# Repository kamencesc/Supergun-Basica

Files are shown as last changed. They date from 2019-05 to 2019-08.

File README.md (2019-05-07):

# Supergun-Basica
Diseño de una Supergun básica.

## Que es un Supergun?
Un Supergun nos permite conectar las antiguas placas de máquinas recreativas a un sistema adaptado, como puede ser a una TV, un monitor LCD, usando Gamepads de consolas, etc...

## Que hace este Supergun?
Tengo otro repositorio en el que intento crear una supergun lo mas completa posible, pero todo empieza por una base y este reprositorio es ela base del otro, por lo tanto tiene unas prestaciones muy básicas, como su propio nombre indica.

Dos puertos para joysticks arcade de 6 botones, 4 direcciones, Start y Select.

Entrada de 6 pins para conecta un Kick Harness.

Botón para seleccionar si jugar con el botón 6 del Kick Harness o de la placa arcade (ej. Bluelf)

Cambio de botones via hardware, nos permite poder cambiar la entre dos distribuciones de botones en el caso de usar un CPO del tipo 6 botones como los de Capcom. Mediante este cambio podemos asignar los 6 botones para usar un juego de lucha de Capcom (modo normal) o bien usar los dos primeros botones de la izquierda de las dos hileras, para juegos de lucha de NeoGeo de 4 botones. **Es importante que los switch estén siempre en la misma posición para evitar doblepulsación**

Salida Jack de 3,5" con selector para audio MONO o STEREO

Salida de video mediante terminales de tornillo, directa del connector JAMMA para su posprocesado externo (ej. usando una GBS8200 y adaptar video de CGA a VGA)

Entrada de corriente mediante terminales de tornillo, +5V +12V -5V y GND. Los -5V no suelen usarse pero lo dejamos por si alguna placa lo requiere.

La placa integra un connector para Kick Harness de CPS2 y así no tener que ir haciendo bricolaje. Este connector tiene que ir arrimado a la derecha del Kick Harness en el modulo CPS2.

Para facilitar la manipulación, se pueden usar switch/palancas externas, por ejemplo en una caja o en un mueble arcade, para así tener mas accesible la configuración de botones o los botones Credit, Test, Servicio y Select+ (cambio de juego en MVS multi cartucho).

# Agradecimientos
En este proyecto se ha usado el conector Jamma disponible en **Shinichi-Ohki** y disponible en su GitHub: https://github.com/Shinichi-Ohki/JAMMA_connector_for_eagle

Teneis un fork de su proyecto en mi github en el que he integrado conectores inversos (los que usa este supergun) y he suprimido el texto (que ademas tenia en la misma cara y lo hacía inteligible): https://github.com/kamencesc/JAMMA_connector_for_eagle

Los "pañeros" de _Crazy Lab_ por aguantar mis preguntas tontas...

**UNTESTED**

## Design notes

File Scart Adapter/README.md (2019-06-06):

# Scart Adapter (jamma rgb2scart)
Con este adaptador tendremos señal de salida en SCART lista para connectar a una TV (no todas son compatibles).

Solo tenemos que llevar los siguientes señales

* R G B
* Sync
* 12V
* Audio R y L (con opción de usar un cable jack-jack, ideal por si usamos placas con salida de audio estereo directo como puede ser CPS2 o algunas MVS)

En la última versión disponible se ha añadido un LM1881 (AKA Sync Stripper) con montaje completamente opcional. El LM1881 usará el canal GREEN (sync on green) para generar una señal de sync mas limpia.

Para que el circuito funcioné como tal deberemos tener los jumpers J1 en posición 1-2 (o un switch si lo prefieres), los componentes son LM1881 en formato DIP8, dos condensadores de 0.1pF, una resistencia de 680k y por seguridad se ha añadido un REG1117 para usar 5V en el LM1881 (aunque tiene una tolerancia de 5-12V)

**UNTESTED**

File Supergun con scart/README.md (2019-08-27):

## Supergun con Scart
**UNTESTED**

Se ha realizado una versión del supergun con scart integrado. Este incluye todo lo del supergun básico ~~excepto que en vez de tener los terminales de RGB, disponemos de salida scart~~, seguimos disfrutando de salida jack 3.5" para el audio, si conectamos un jack, el audio del Scart queda deshabilitado.

Se han incluido Screw Terminals para dar salida a la señal directa del connector jamma, ademas de tener un selector de Sync, podemos seleccionar salida desde el potenciometro R10 o directo del jamma. En caso de usar los Screw Terminals y no se quiere instalar el scart, R5, R6, R7, R8 y R9 son completamente prescindibles.

~~Por espacio no se ha añadido un LM1881, sin prescindir de alguna otra opción no hay sitio en el diseño actual de la placa, se podria añadir a modo SMD pero lo que se pretende con esta placa es que sea de fácil montaje, con todos sus componentes DIP (con agujero).~~

Se ha añadido un LM1881 para Syn On Green en el scart, ademas hay un switch para seleccionar usar el LM1881 (CSYNC) o sync directo de jamma, esta última opción es para facilitar el uso con el OSSC.

Al igual que la versión básica se mantiene el Kick Harness para CPS2 (este Kick Harness es solo para los botones de patada y volumen, no para juegos de 4 Players), simplemente recortar las 2 placas adicionales, Soldar los pinheader correspondientes (hembra para la parte de CPS2 y la del supergun depende del usuario), soldar entre ellas los botones de patada del P1 y P2. La parte de CPS2 tiene para mapear botones de volumen (V- y V+).

Añadir que no todas las TVs pueden ser compatibles.

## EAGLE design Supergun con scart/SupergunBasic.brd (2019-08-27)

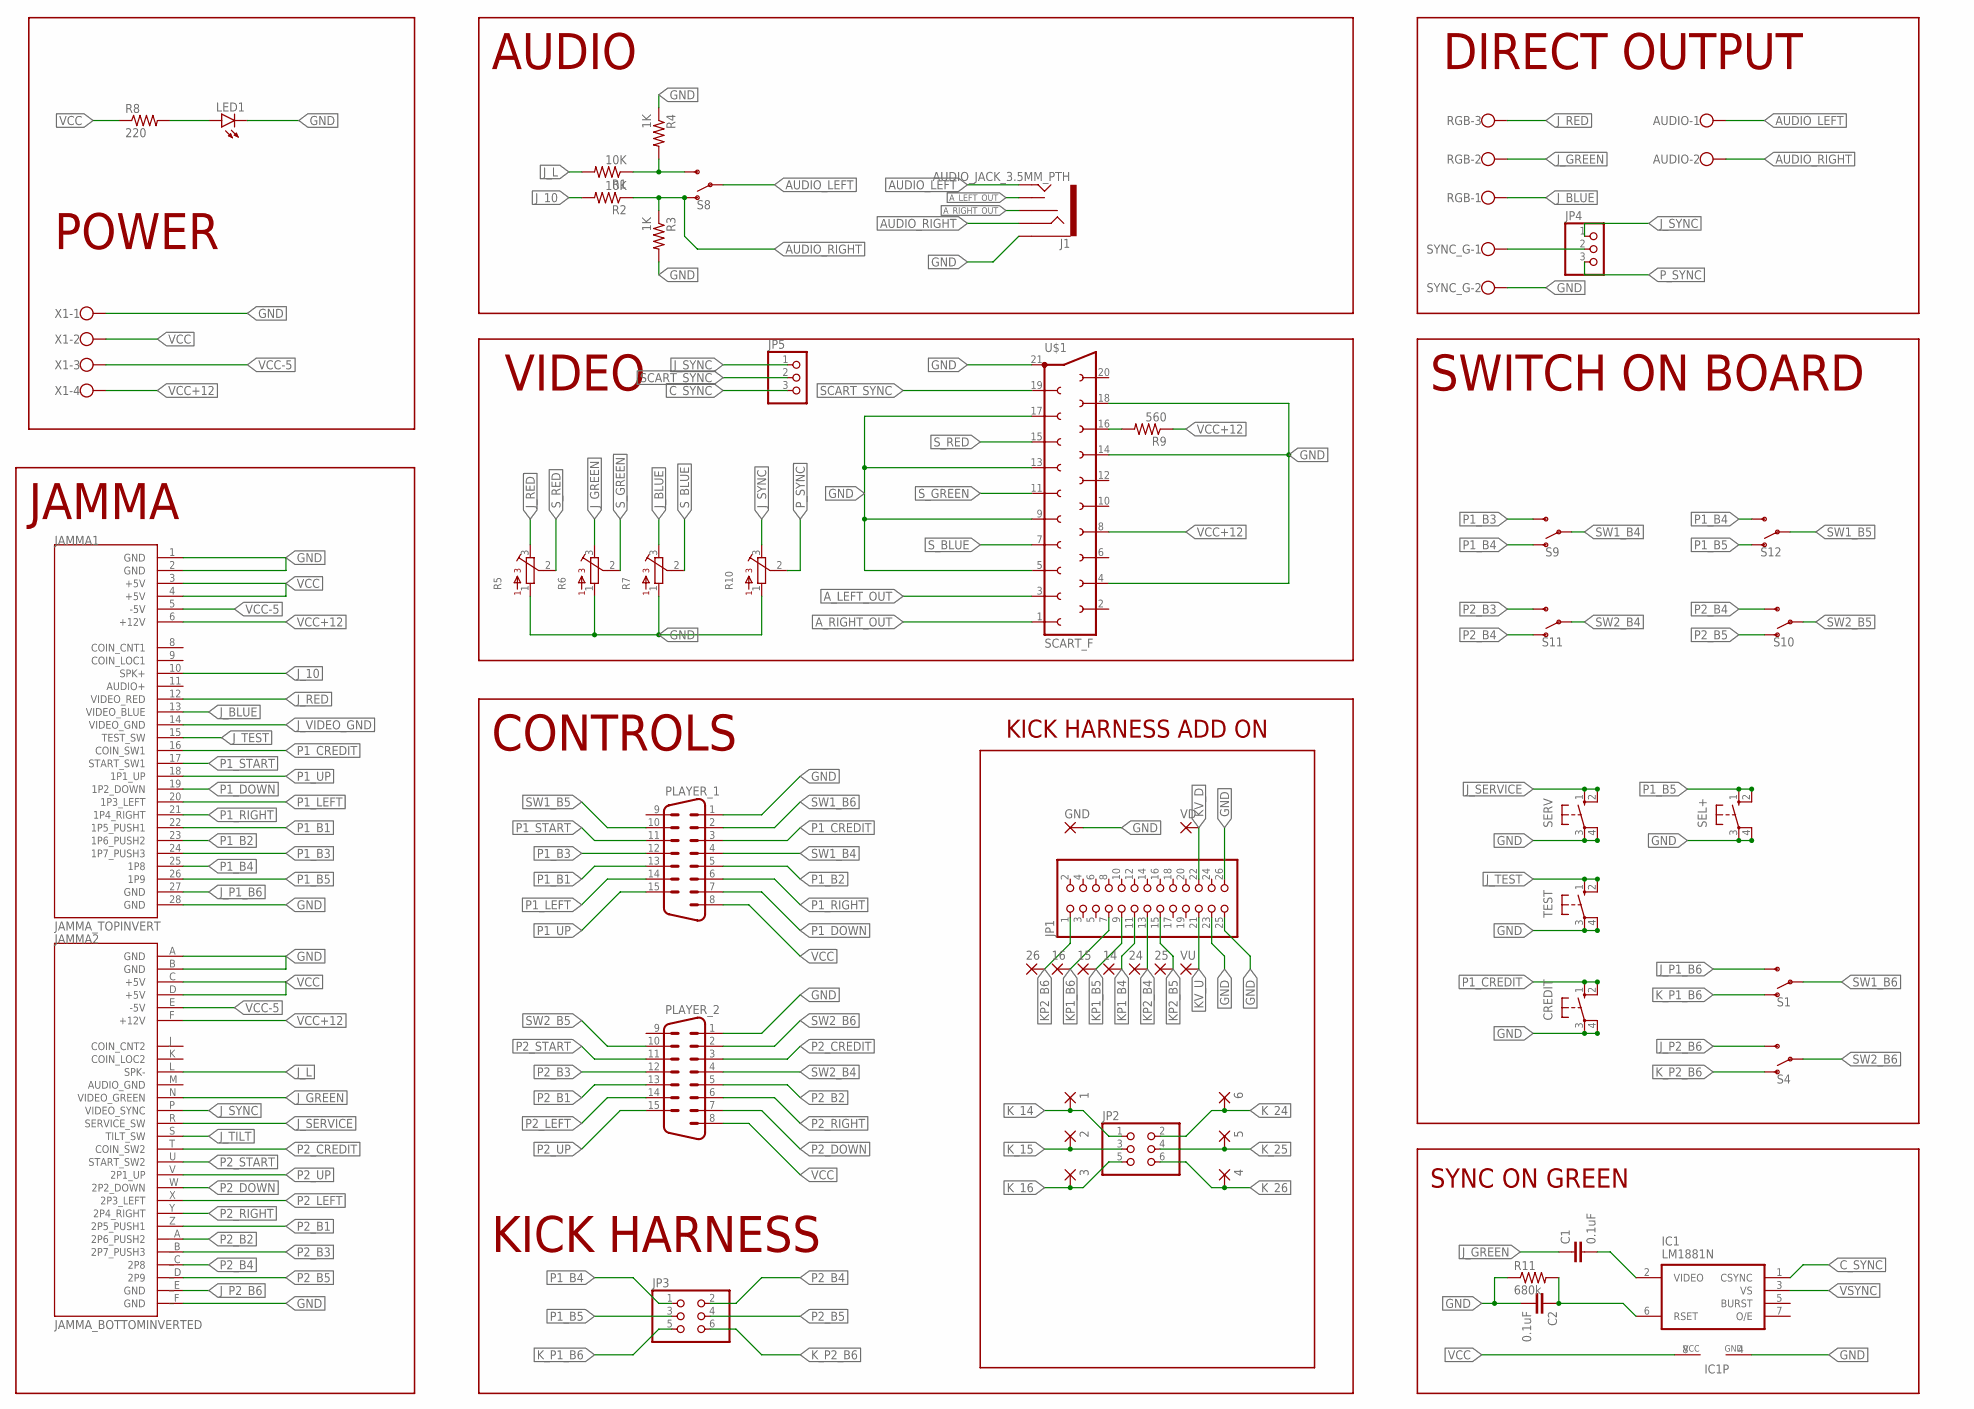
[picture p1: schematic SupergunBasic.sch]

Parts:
1, 2, 3, 4, 5, 6, 14, 15, 16, 24, 25, 26: SMD2; SMD1,27-2,54
AUDIO: W237-102
C1, C2: 0.1uF; CAP-PTH-SMALL-KIT
CREDIT: 10-XX; B3F-10XX
GND: SMD2; SMD1,27-2,54
IC1: LM1881N; DIL08
J1: AUDIO_JACK_3.5MM_PTH; AUDIO-JACK
JAMMA1: JAMMA_TOPINVERT; JAMMA_TOP_INV
JAMMA2: JAMMA_BOTTOMINVERTED; JAMMA_BOTTOM_INV
JP1: PINHD-2X13; 2X13
JP2, JP3: PINHD-2X3; 2X03
JP4, JP5: PINHD-1X3; 1X03
LED1: LEDLD260; LD260
PLAYER_1, PLAYER_2: M15HP
R1, R2: 10K; 0204/7
R3, R4: 1K; 0204/7
R5, R6, R7, R10: 3362P
R8: 220; 0204/7
R9: 560; 0204/7
R11: 680k; 0204/7
RGB: W237-103
S1, S4, S8, S9, S10, S11, S12: SWITCH-SPDT-PTH-11.6X4.0MM; SWITCH_SPDT_PTH_11.6X4.0MM
SEL+: 10-XX; B3F-10XX
SERV: 10-XX; B3F-10XX
SYNC_G: W237-102
TEST: 10-XX; B3F-10XX
U$1: SCART_F
VD: SMD2; SMD1,27-2,54
VU: SMD2; SMD1,27-2,54
X1: W237-4

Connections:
AUDIO_LEFT: AUDIO.1, J1.TIP, S8.2
AUDIO_RIGHT: AUDIO.2, J1.RING, R2.1, R3.1, S8.1 (O)
A_LEFT_OUT: J1.TSH, U$1.3
A_RIGHT_OUT: J1.RSH, U$1.1
C_SYNC: IC1.1 (CSYNC), JP5.3
DIRECT_SYNC: JP4.2, SYNC_G.1
GND: C2.2, CREDIT.3, CREDIT.4 (P1), GND.1, IC1.4 (GND), J1.SLEEVE, JAMMA1.1 (GND), JAMMA1.2 (GND), JAMMA1.28 (GND), JAMMA2.A (GND), JAMMA2.B (GND), JAMMA2._F (GND), JP1.23, JP1.25, JP1.26, LED1.K (C), PLAYER_1.1, PLAYER_2.1, R3.2, R4.1, R5.1, R6.1, R7.1, R10.1, R11.1, SEL+.3, SEL+.4 (P1), SERV.3, SERV.4 (P1), SYNC_G.2, TEST.3, TEST.4 (P1), U$1.4, U$1.5, U$1.9, U$1.13, U$1.14, U$1.17, U$1.18, U$1.21, X1.1
J_10: JAMMA1.10 (SPK+), R2.2
J_BLUE: JAMMA1.13 (VIDEO_BLUE), R7.3, RGB.1
J_GREEN: C1.1, JAMMA2.N (VIDEO_GREEN), R6.3, RGB.2
J_L: JAMMA2.L (SPK-), R1.2
J_P1_B6: JAMMA1.27 (GND), S1.3 (S)
J_P2_B6: JAMMA2._E (GND), S4.3 (S)
J_RED: JAMMA1.12 (VIDEO_RED), R5.3, RGB.3
J_SERVICE: JAMMA2.R (SERVICE_SW), SERV.1 (S), SERV.2 (S1)
J_SYNC: JAMMA2.P (VIDEO_SYNC), JP4.1, JP5.1, R10.3
J_TEST: JAMMA1.15 (TEST_SW), TEST.1 (S), TEST.2 (S1)
J_TILT: JAMMA2.S (TILT_SW)
J_VIDEO_GND: JAMMA1.14 (VIDEO_GND)
KP1_B4: 14.1, JP1.11
KP1_B5: 15.1, JP1.9
KP1_B6: 16.1, JP1.7
KP2_B4: 24.1, JP1.13
KP2_B5: 25.1, JP1.15
KP2_B6: 26.1, JP1.1
KV_D: JP1.22, VD.1
KV_U: JP1.21, VU.1
K_14: 1.1, JP2.1
K_15: 2.1, JP2.3
K_16: 3.1, JP2.5
K_24: 6.1, JP2.2
K_25: 5.1, JP2.4
K_26: 4.1, JP2.6
K_P1_B6: JP3.5, S1.1 (O)
K_P2_B6: JP3.6, S4.1 (O)
unnamed: LED1.A, R8.2
unnamed: C2.1, IC1.6 (RSET), R11.2
unnamed: C1.2, IC1.2 (VIDEO)
P1_B1: JAMMA1.22 (1P5_PUSH1), PLAYER_1.13
P1_B2: JAMMA1.23 (1P6_PUSH2), PLAYER_1.5
P1_B3: JAMMA1.24 (1P7_PUSH3), PLAYER_1.12, S9.3 (S)
P1_B4: JAMMA1.25 (1P8), JP3.1, S9.1 (O), S12.3 (S)
P1_B5: JAMMA1.26 (1P9), JP3.3, S12.1 (O), SEL+.1 (S), SEL+.2 (S1)
P1_CREDIT: CREDIT.1 (S), CREDIT.2 (S1), JAMMA1.16 (COIN_SW1), PLAYER_1.3
P1_DOWN: JAMMA1.19 (1P2_DOWN), PLAYER_1.7
P1_LEFT: JAMMA1.20 (1P3_LEFT), PLAYER_1.14
P1_RIGHT: JAMMA1.21 (1P4_RIGHT), PLAYER_1.6
P1_START: JAMMA1.17 (START_SW1), PLAYER_1.11
P1_UP: JAMMA1.18 (1P1_UP), PLAYER_1.15
P2_B1: JAMMA2.Z (2P5_PUSH1), PLAYER_2.13
P2_B2: JAMMA2._A (2P6_PUSH2), PLAYER_2.5
P2_B3: JAMMA2._B (2P7_PUSH3), PLAYER_2.12, S11.3 (S)
P2_B4: JAMMA2._C (2P8), JP3.2, S10.3 (S), S11.1 (O)
P2_B5: JAMMA2._D (2P9), JP3.4, S10.1 (O)
P2_CREDIT: JAMMA2.T (COIN_SW2), PLAYER_2.3
P2_DOWN: JAMMA2.W (2P2_DOWN), PLAYER_2.7
P2_LEFT: JAMMA2.X (2P3_LEFT), PLAYER_2.14
P2_RIGHT: JAMMA2.Y (2P4_RIGHT), PLAYER_2.6
P2_START: JAMMA2.U (START_SW2), PLAYER_2.11
P2_UP: JAMMA2.V (2P1_UP), PLAYER_2.15
P_SYNC: JP4.3, R10.2
SCART_FAST_SW: R9.2, U$1.16
SCART_SYNC: JP5.2, U$1.19
STR_LEFT: R1.1, R4.2, S8.3 (S)
SW1_B4: PLAYER_1.4, S9.2
SW1_B5: PLAYER_1.10, S12.2
SW1_B6: PLAYER_1.2, S1.2
SW2_B4: PLAYER_2.4, S11.2
SW2_B5: PLAYER_2.10, S10.2
SW2_B6: PLAYER_2.2, S4.2
S_BLUE: R7.2, U$1.7
S_GREEN: R6.2, U$1.11
S_RED: R5.2, U$1.15
VCC: IC1.8 (VCC), JAMMA1.3 (+5V), JAMMA1.4 (+5V), JAMMA2.C (+5V), JAMMA2.D (+5V), PLAYER_1.8, PLAYER_2.8, R8.1, X1.2
VCC+12: JAMMA1.6 (+12V), JAMMA2.F (+12V), R9.1, U$1.8, X1.4
VCC-5: JAMMA1.5 (-5V), JAMMA2.E (-5V), X1.3
VSYNC: IC1.3 (VS)

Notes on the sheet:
CONTROLS
SWITCH ON BOARD
JAMMA
VIDEO
AUDIO
POWER
KICK HARNESS
DIRECT OUTPUT
KICK HARNESS ADD ON
SYNC ON GREEN

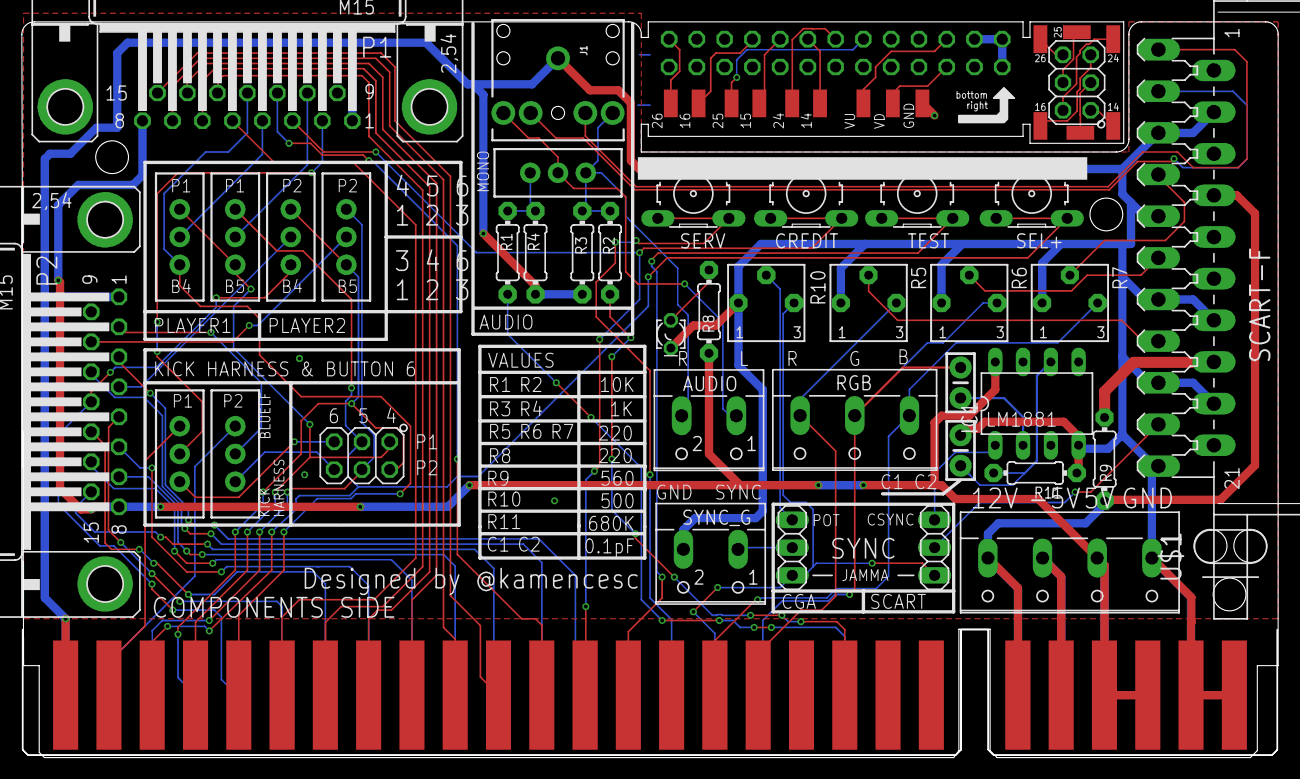
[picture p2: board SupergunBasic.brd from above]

Board: 2 copper layers, 114.9 x 67.3 mm, 56 parts (1 on the bottom side), 74 nets.

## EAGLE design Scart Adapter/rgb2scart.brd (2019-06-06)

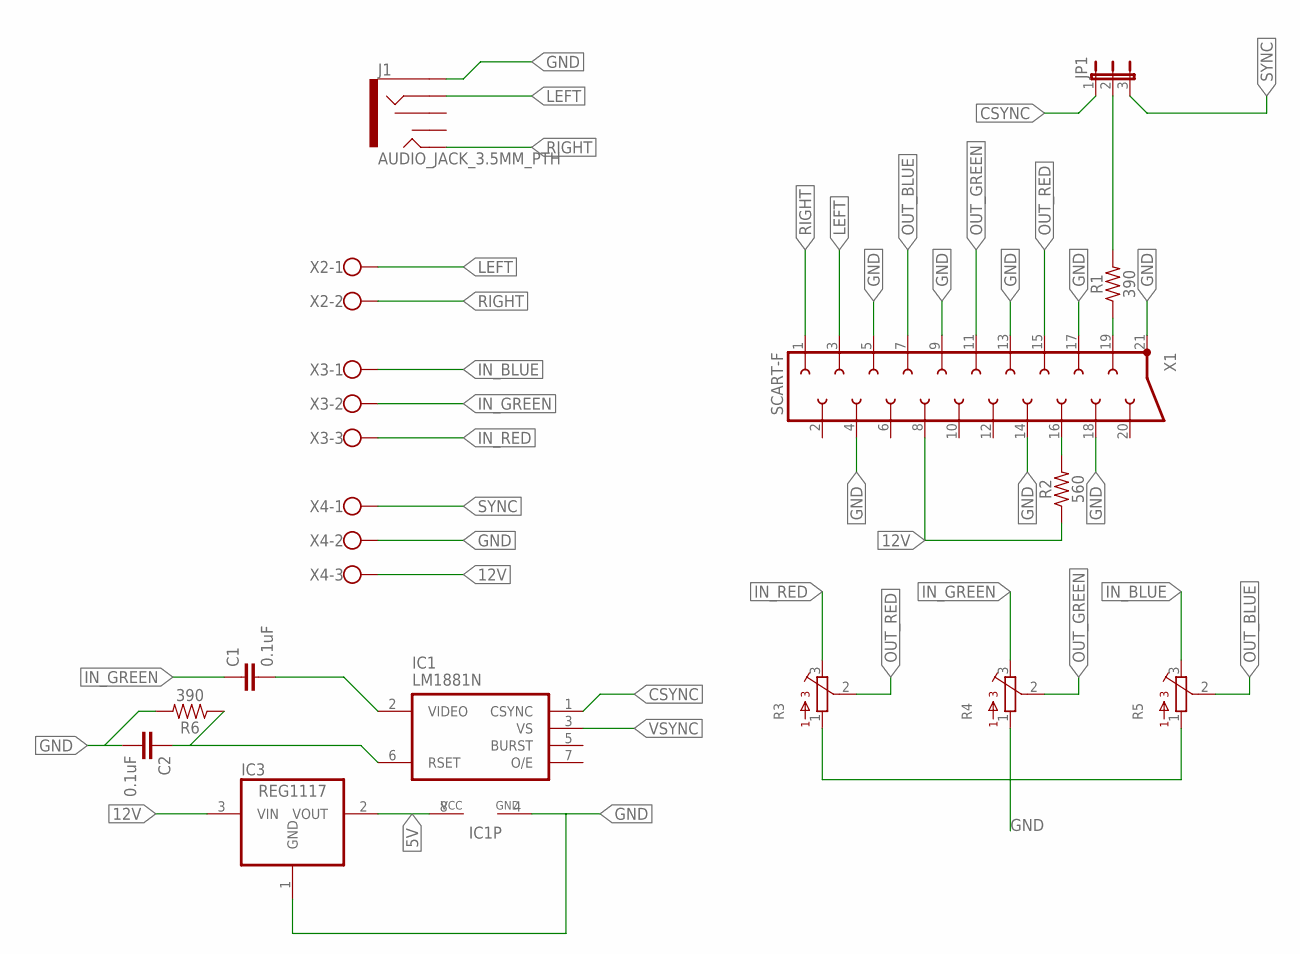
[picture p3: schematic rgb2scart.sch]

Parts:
C1, C2: 0.1uF; CAP-PTH-SMALL-KIT
IC1: LM1881N; DIL08
IC3: REG1117; SOT223
J1: AUDIO_JACK_3.5MM_PTH; AUDIO-JACK
JP1: JP2E; JP2
R1, R6: 390; AXIAL-0.3
R2: 560; AXIAL-0.3
R3, R4, R5: 3362P
X1: SCART-F
X2: W237-102
X3, X4: W237-103

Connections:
5V: IC1.8 (VCC), IC3.2 (VOUT)
12V: IC3.3 (VIN), R2.P$1 (1), X1.8, X4.3
CSYNC: IC1.1 (CSYNC), JP1.1
GND: C2.2, IC1.4 (GND), IC3.1 (GND), J1.SLEEVE, R3.1, R4.1, R5.1, R6.P$2 (2), X1.4, X1.5, X1.9, X1.13, X1.14, X1.17, X1.18, X1.21, X4.2
IN_BLUE: R5.3, X3.1
IN_GREEN: C1.1, R4.3, X3.2
IN_RED: R3.3, X3.3
LEFT: J1.RING, X1.3, X2.1
unnamed: JP1.2, R1.P$2 (2)
unnamed: C2.1, IC1.6 (RSET), R6.P$1 (1)
unnamed: C1.2, IC1.2 (VIDEO)
unnamed: R2.P$2 (2), X1.16
unnamed: R1.P$1 (1), X1.19
OUT_BLUE: R5.2, X1.7
OUT_GREEN: R4.2, X1.11
OUT_RED: R3.2, X1.15
RIGHT: J1.TIP, X1.1, X2.2
SYNC: JP1.3, X4.1
VSYNC: IC1.3 (VS)

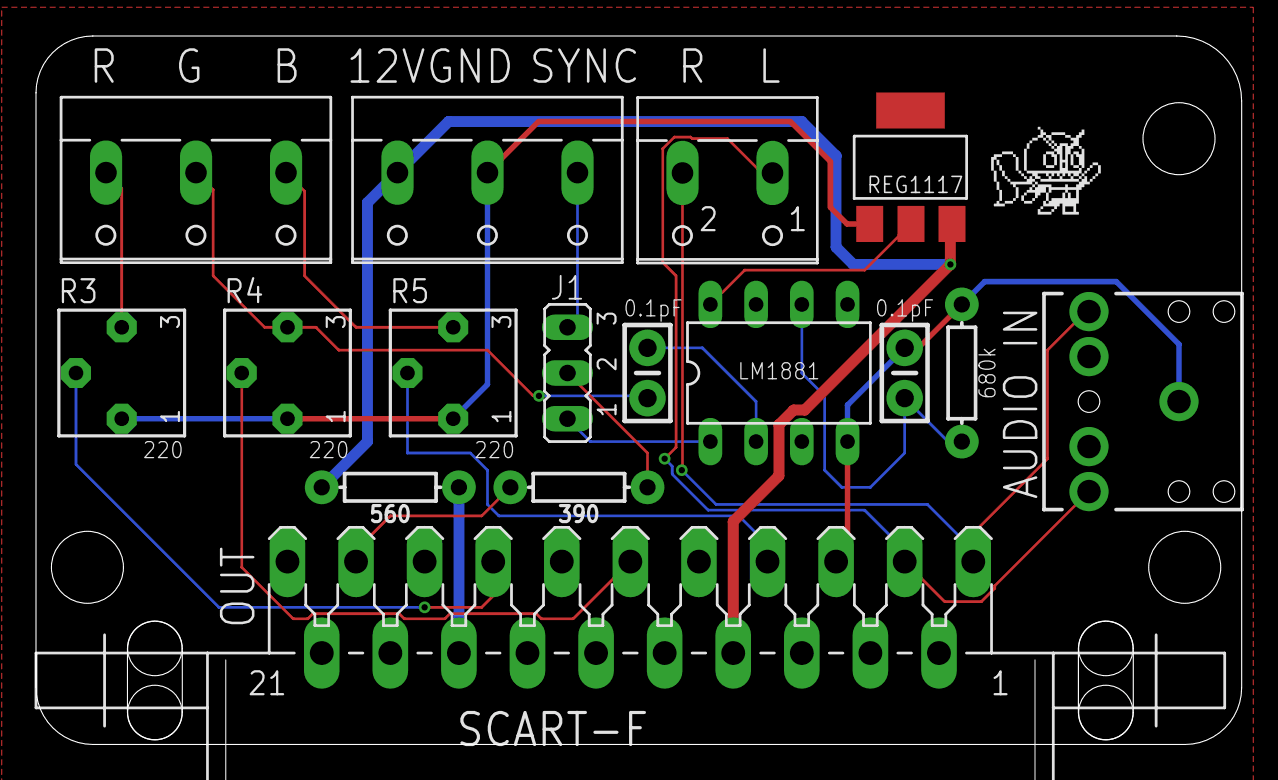
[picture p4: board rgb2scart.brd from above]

Board: 2 copper layers, 67.0 x 39.4 mm, 16 parts (0 on the bottom side), 18 nets.

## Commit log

2019-05-03 SCH & BRD
    Primera versión de esta supergun básica, subidos sch y brd.
    [SupergunBasic.brd, SupergunBasic.sch]
2019-05-03 Delete SupergunBasic.brd
    Error de diseño....
    [SupergunBasic.brd]
2019-05-05 rgb2scart para jamma
    Añadido el SCH y el BRD
    [rgb2scart.brd, rgb2scart.sch]
2019-05-05 Supergun Basica
    Añadidos el sch y brd, se ha corregido el error detectado en el puerto JAMMA (estaba invertido), ahora se puede soldar un connector JAMMA hembra para así conectar directamente nuestras placas JAMMA.
    [SupergunBasic.brd, SupergunBasic.sch]
2019-05-05 Add files via upload
    Se han marcado unos puntos en la PCB por si se quiere tener salida directa RGB del jamma en el caso de no querer usar el Scart
    [SupergunBasic.brd]
2019-05-07 Add files via upload
    Actualizados sch y brd.
    En el esquema se han icluïdo 2 subplacas que tienen que cortarse. Estas subplacas permiten conectarse al Kick Harness de CPS2. La pequeña va conectada a la Supergun (simplemente hacer coincidir los 2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
    [SupergunBasic.brd, SupergunBasic.sch]
2019-06-06 Add files via upload
    Actualización
    [SupergunBasic.brd, SupergunBasic.sch]
2019-06-06 Add files via upload
    He estado trabajando en la versión con Scart, es mas fácil quitar que añadir cosas, así que en el momento de subir esta versión, es identica a la Scart pero sin los requisitos de este.
    [SupergunBasic.brd, SupergunBasic.sch]
2019-06-25 Add files via upload
    Minor changes
    [SupergunBasic.brd]
2019-08-27 Add files via upload
    There ara some changesr since las versión, now there's a lm1881 sync stripper to get Sync On Green to Scart Connector. But if you are using a OSSC theres a switch to select Jamma Sync (original) or Csync (LM1881)
    Now there's a LED to bring light to the PCB!
    Minir improvements on design
    [SupergunBasic.brd, SupergunBasic.sch]
2019-08-27 Add files via upload
    Optional LM1881 to scart connector, now you can select between lm1881 or jamma sync
    LED added
    Other improvements
    [SupergunBasic.brd, SupergunBasic.sch]
2019-08-27 Add files via upload
    GND pad on the Kick Harness
    [SupergunBasic.brd, SupergunBasic.sch]
2019-08-27 Add files via upload
    +12V Width changed to 30mil
    [SupergunBasic.brd, SupergunBasic.sch]

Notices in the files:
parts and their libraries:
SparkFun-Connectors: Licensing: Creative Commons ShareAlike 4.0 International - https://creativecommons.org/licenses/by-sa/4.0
